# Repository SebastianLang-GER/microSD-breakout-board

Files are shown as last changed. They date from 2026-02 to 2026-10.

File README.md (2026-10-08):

# microSD breakout board
This is a compact microSD breakout board for both directions.  
It can also be used as a sniffer in between a host and a microSD card for analyzing signals or performing tests.  
The PCB is optimized for signal integrity with coplanar single ended impedance matching (50 Ω ±10 %).  

| Top | Bottom |
| :---: | :---: |
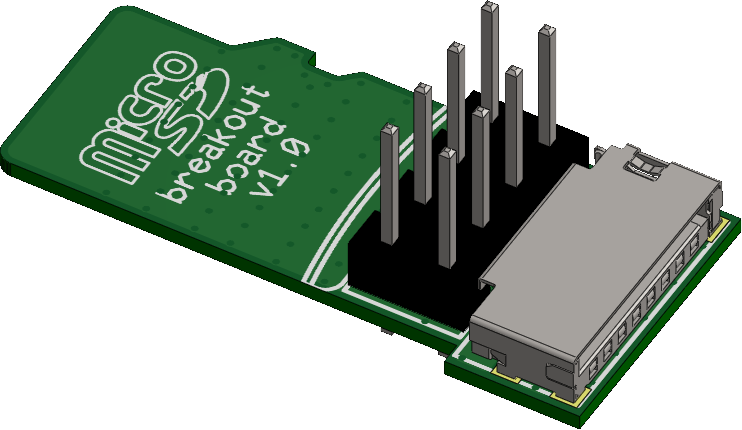
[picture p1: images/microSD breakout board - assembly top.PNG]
microSD breakout board
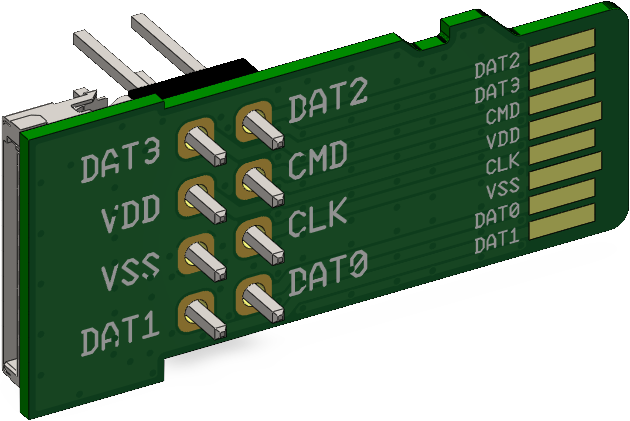
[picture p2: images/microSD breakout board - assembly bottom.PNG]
microSD breakout board
|  |  |

## Components  
Two optional components can be placed on the PCB:
- microSD card header `Molex 475710001`
- 2x4 2.54 mm pin header (e.g. `Molex 10897080`)

## Manufacturing
The PCB has the following properties:
- Size: 26.5 x 12.5 mm
- PCB thickness: 0.8 mm
- Layers: 2
- Copper weight: 1 oz
- Min. via hole size: ⌀ 0.3 mm
- Min. via diameter: ⌀ 0.4 mm
- Min. trace width: 0.4326 mm
- Min. distance between traces or pads: 0.127 mm
- Min. distance to board outline: 0.3 mm

Gerber files (RS-274X) are available [here](/electronics/production/).

The impedance was calculated for the standard 2 layer, 0.8 mm stack-up from JLCPCB: "JLC0208".

## Licence
This repository is in public domain.  
[Read more](/LICENSE)  
open source hardware logo

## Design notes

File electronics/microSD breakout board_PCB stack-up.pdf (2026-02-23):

PCB stack-up
Project: | microSD breakout board
Material: FR-4 | 0,716 mm
| mil | mm
Silkscreen | 0,1 0,003
Solder Mask | 0,4 0,010 | 3,8
1 | Copper | 0,6 0,015 | 1 oz
Core | 26 | 0,665 KB-6164 | 4,8 | 135 °C
2 | Copper | 0,6 0,015 | 1 oz
Solder Mask | 0,4 0,010 | 3,8
Silkscreen | 0,1 0,003

Solder Mask Bottom
Silkscreen Bottom

Thickness:
Name: | Layer: Type:
Silkscreen Top
Solder Mask Top
Copper Top

Dielectric

Copper Bottom

Material: | TG: Dk/εr: Weight:

Total Thickness:

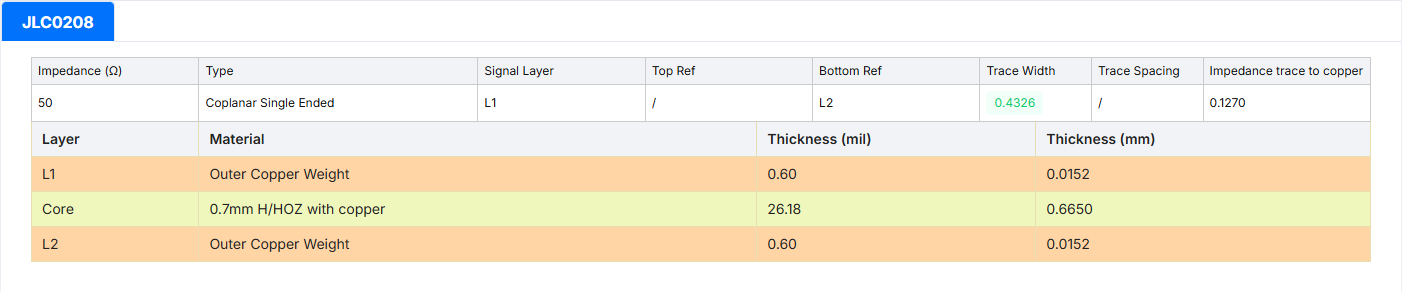
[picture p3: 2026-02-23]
electronics/microSD breakout board_impedance.png

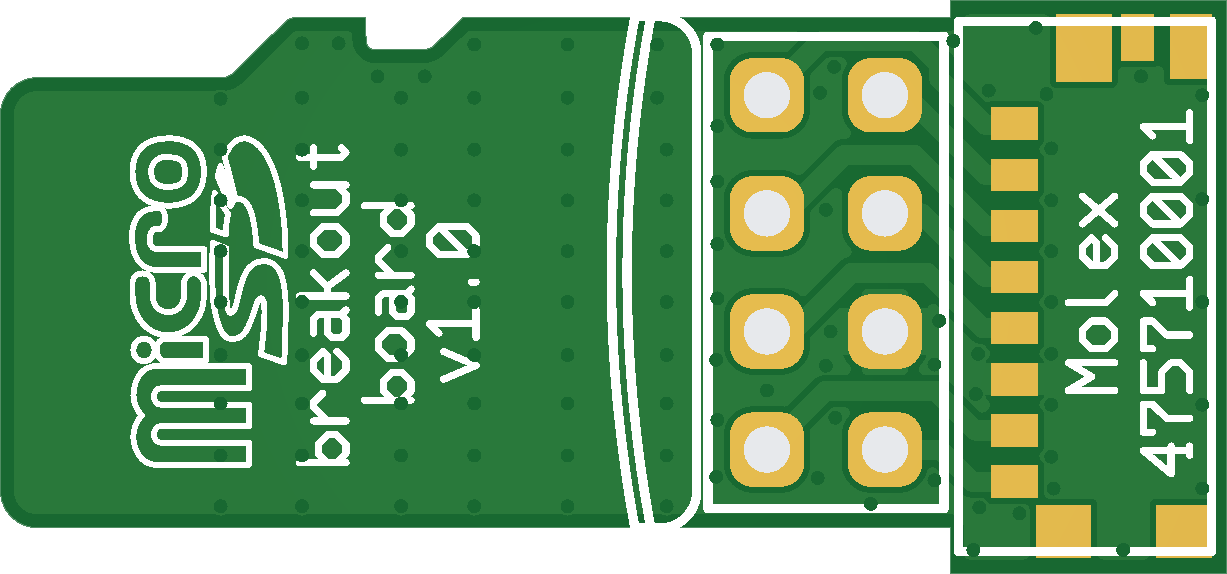
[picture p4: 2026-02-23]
images/microSD breakout board - PCB top.png

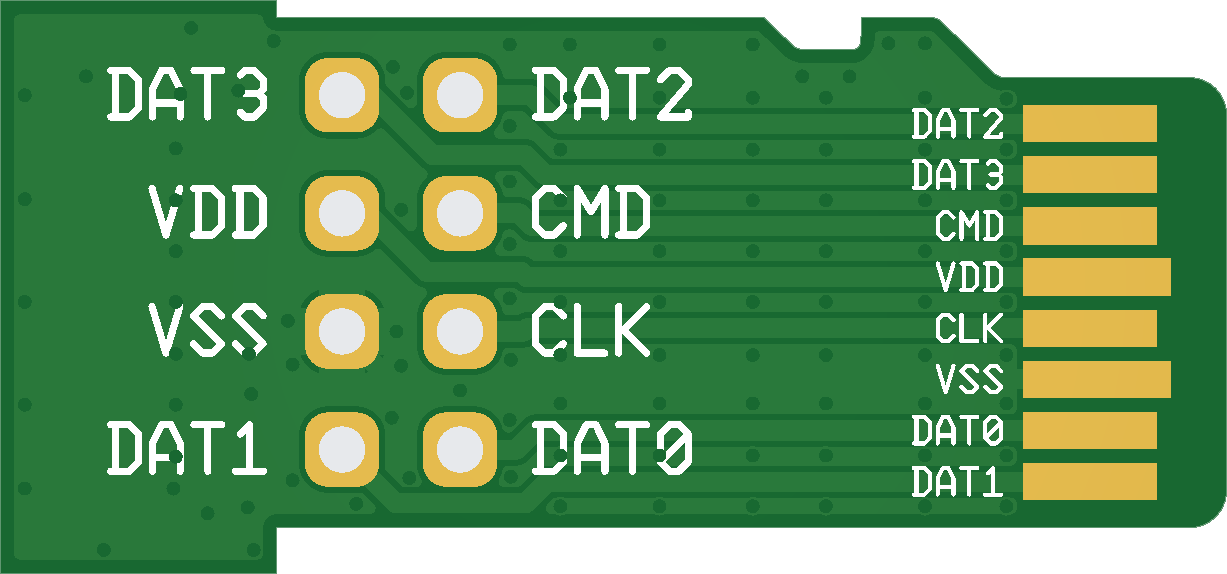
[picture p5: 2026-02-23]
images/microSD breakout board - PCB bottom.png

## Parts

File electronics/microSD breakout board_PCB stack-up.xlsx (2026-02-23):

PCB stack-up
Project: | microSD breakout board
Material: | FR-4 |  | Total Thickness: |  | 0.716 | mm
Name: |  | Layer: | Type: | Thickness: |  | Material: | Dk/εr: | Weight: | TG:
 |  |  |  | mil | mm
Silkscreen Top |  |  | Silkscreen | 0.1 | 0.003
Solder Mask Top |  |  | Solder Mask | 0.4 | 0.010 |  | 3.8
Copper Top |  | 1 | Copper | 0.6 | 0.015 |  |  | 1 oz
Dielectric |  |  | Core | 26.18 | 0.665 | KB-6164 | 4.8 |  | 135 °C
Copper Bottom |  | 2 | Copper | 0.6 | 0.015 |  |  | 1 oz
Solder Mask Bottom |  |  | Solder Mask | 0.4 | 0.010 |  | 3.8
Silkscreen Bottom |  |  | Silkscreen | 0.1 | 0.003

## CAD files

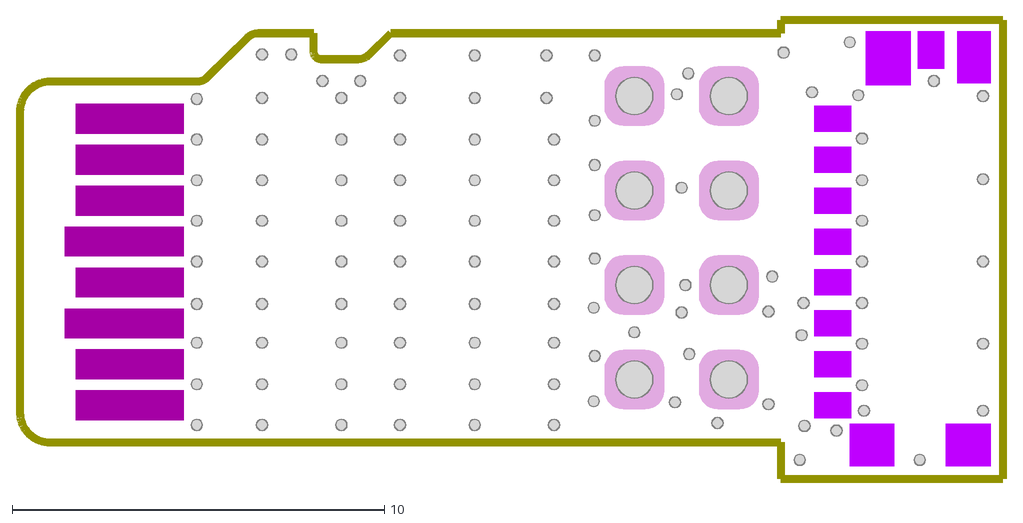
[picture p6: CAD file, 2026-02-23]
electronics/production/microSD breakout board.dxf
26.6 x 12.5

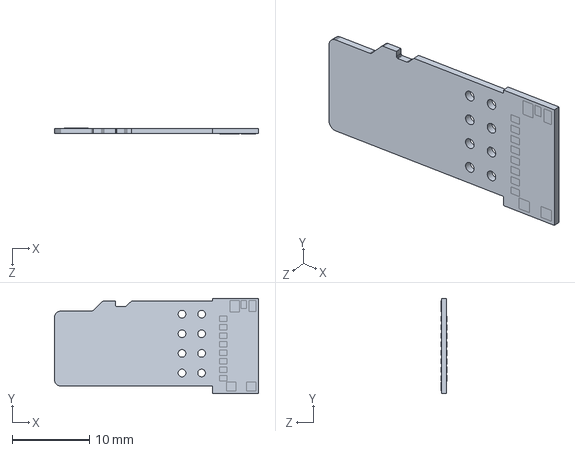
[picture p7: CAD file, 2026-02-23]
mechanics/PCB.SLDPRT
26.4 x 12.3 x 0.72 mm

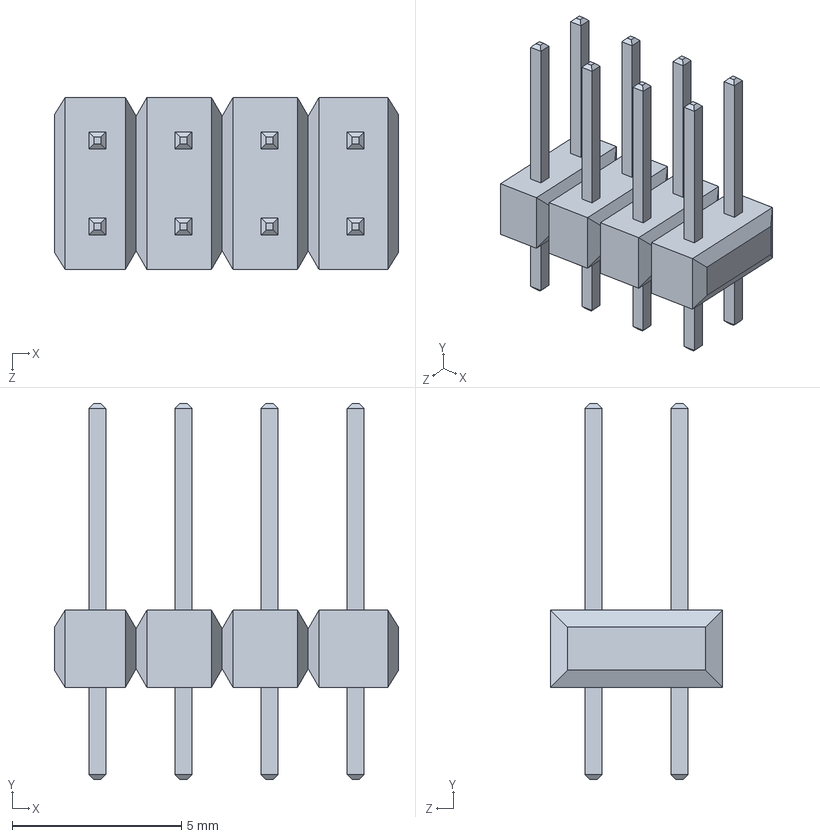
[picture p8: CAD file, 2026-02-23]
mechanics/Molex 10897080.SLDPRT
10.2 x 11.1 x 5.08 mm

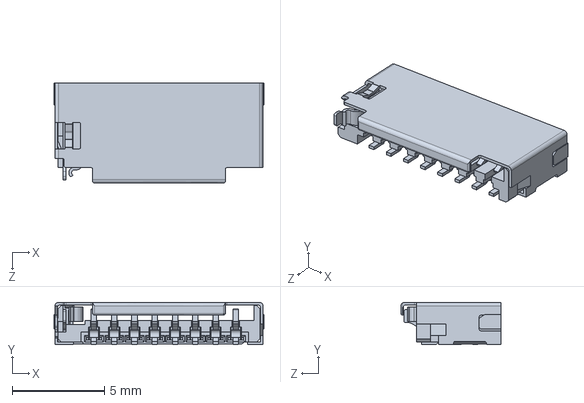
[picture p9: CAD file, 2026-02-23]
mechanics/Molex 475710001.SLDPRT
11.4 x 2.30 x 5.45 mm

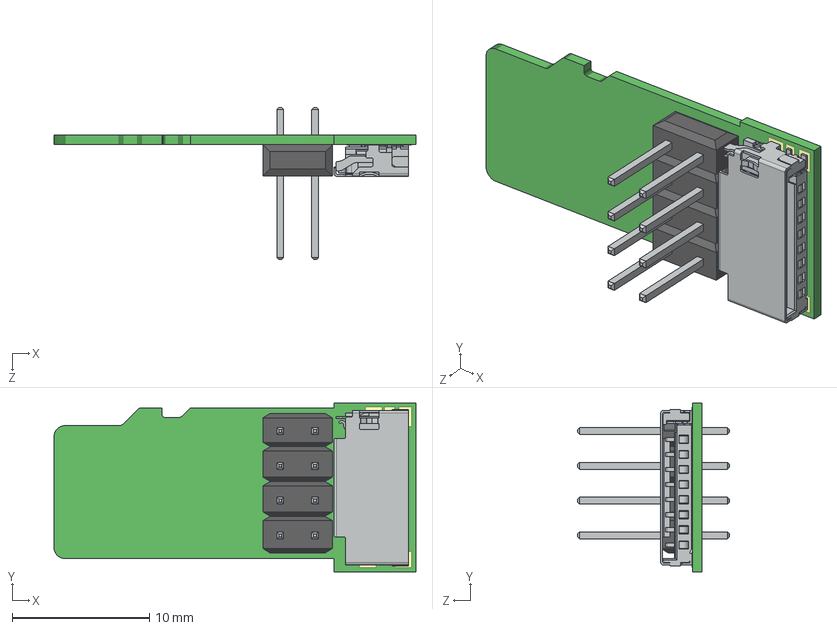
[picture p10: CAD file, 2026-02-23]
mechanics/microSD breakout board.STEP
26.4 x 12.3 x 11.1 mm
PCB
Molex 10897080
Molex 475710001

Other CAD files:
mechanics/microSD breakout board.SLDASM

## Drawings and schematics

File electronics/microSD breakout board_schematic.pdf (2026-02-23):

X2

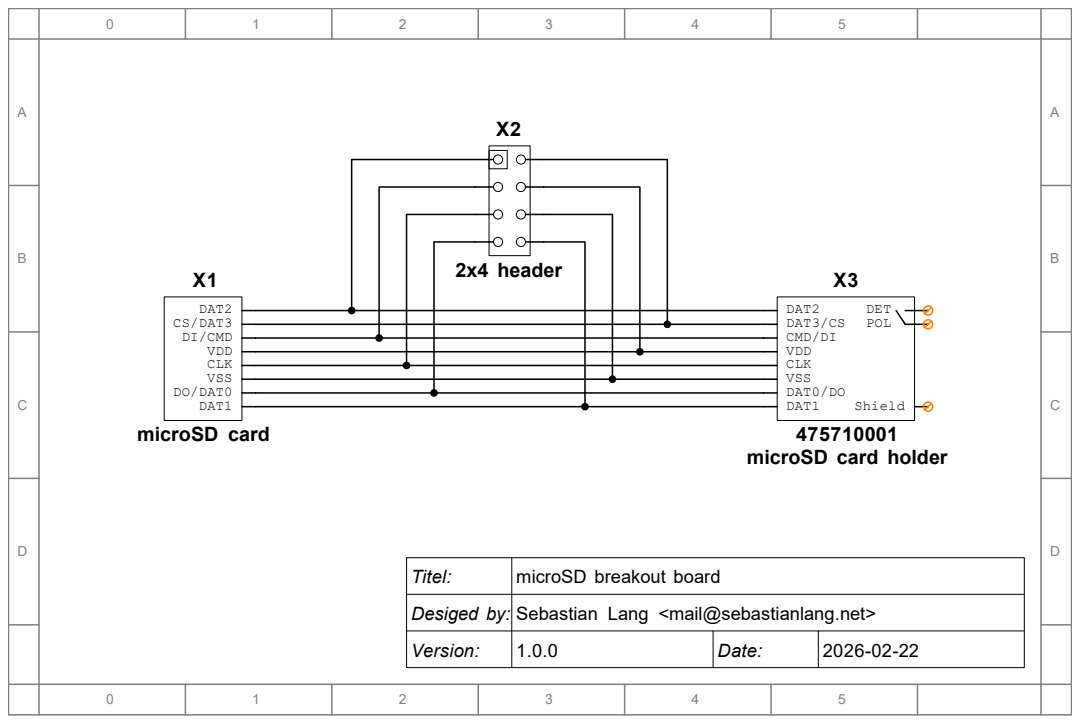
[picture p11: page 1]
D D Titel:; Desiged by:; Date:; Version:; microSD card; DAT2 CS/DAT3 DI/CMD VDD CLK VSS DO/DAT0 DAT1; 2x4 header; 475710001 microSD card holder; DAT2 DAT3/CS CMD/DI VDD CLK VSS DAT0/DO DAT1; POL; DET; Shield

microSD breakout board
Sebastian Lang <mail@sebastianlang.net>

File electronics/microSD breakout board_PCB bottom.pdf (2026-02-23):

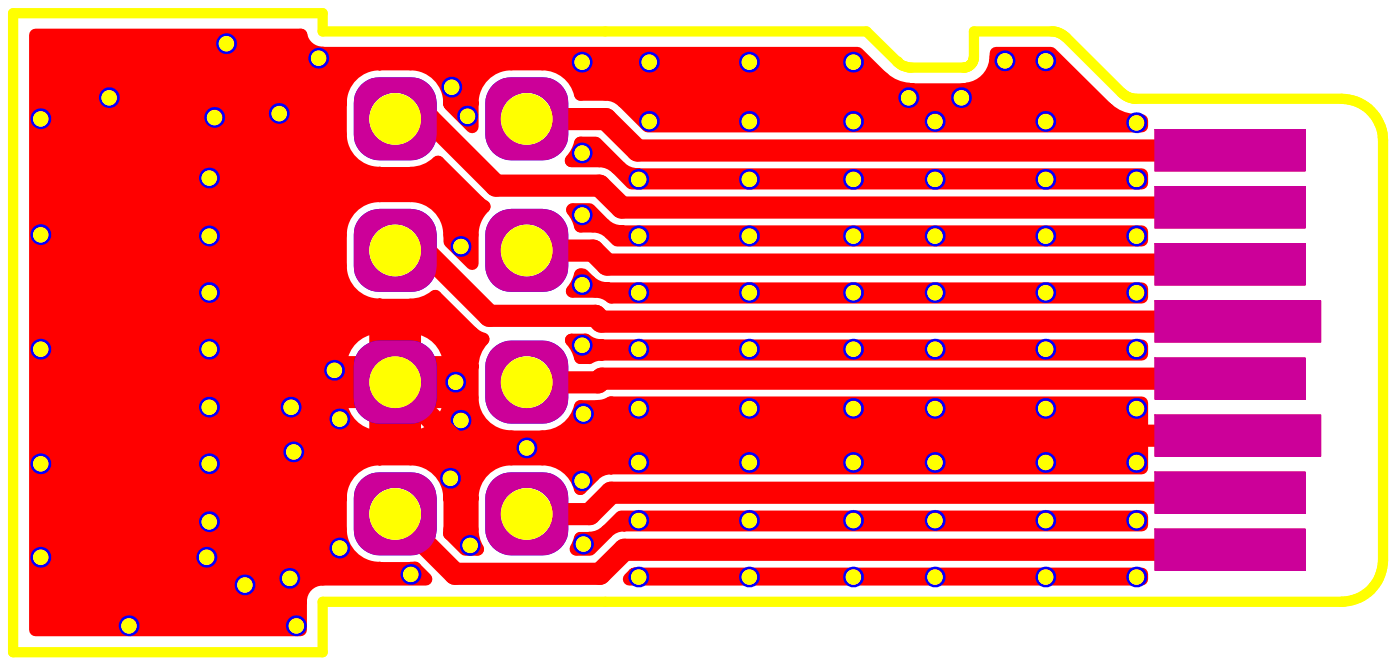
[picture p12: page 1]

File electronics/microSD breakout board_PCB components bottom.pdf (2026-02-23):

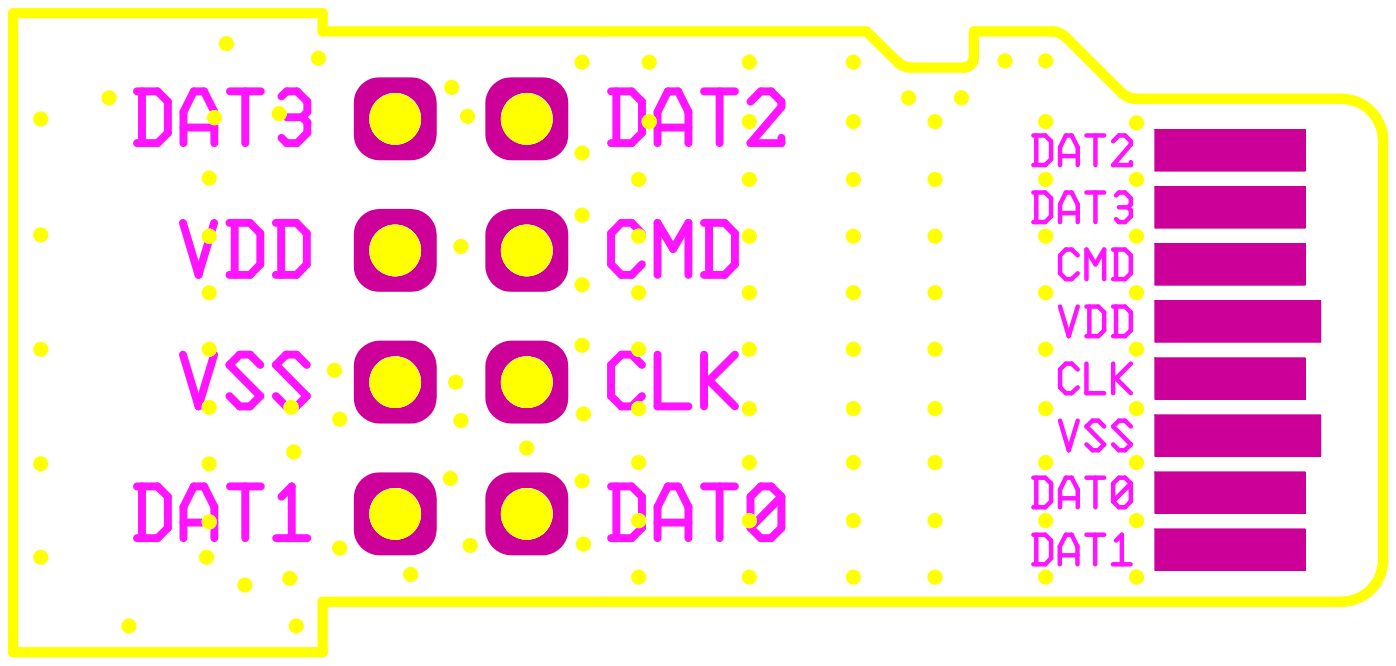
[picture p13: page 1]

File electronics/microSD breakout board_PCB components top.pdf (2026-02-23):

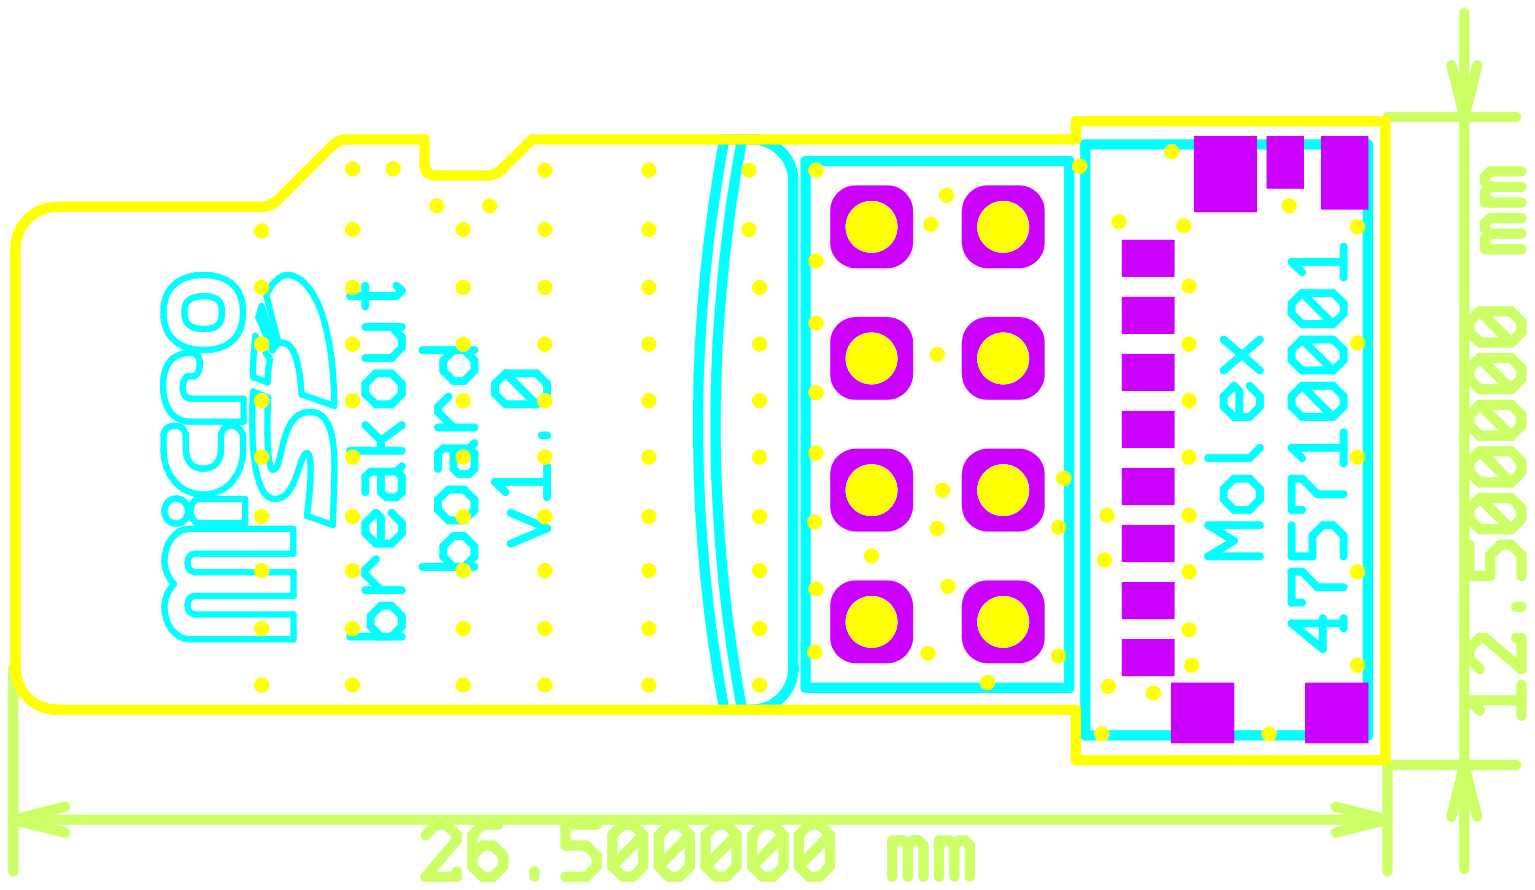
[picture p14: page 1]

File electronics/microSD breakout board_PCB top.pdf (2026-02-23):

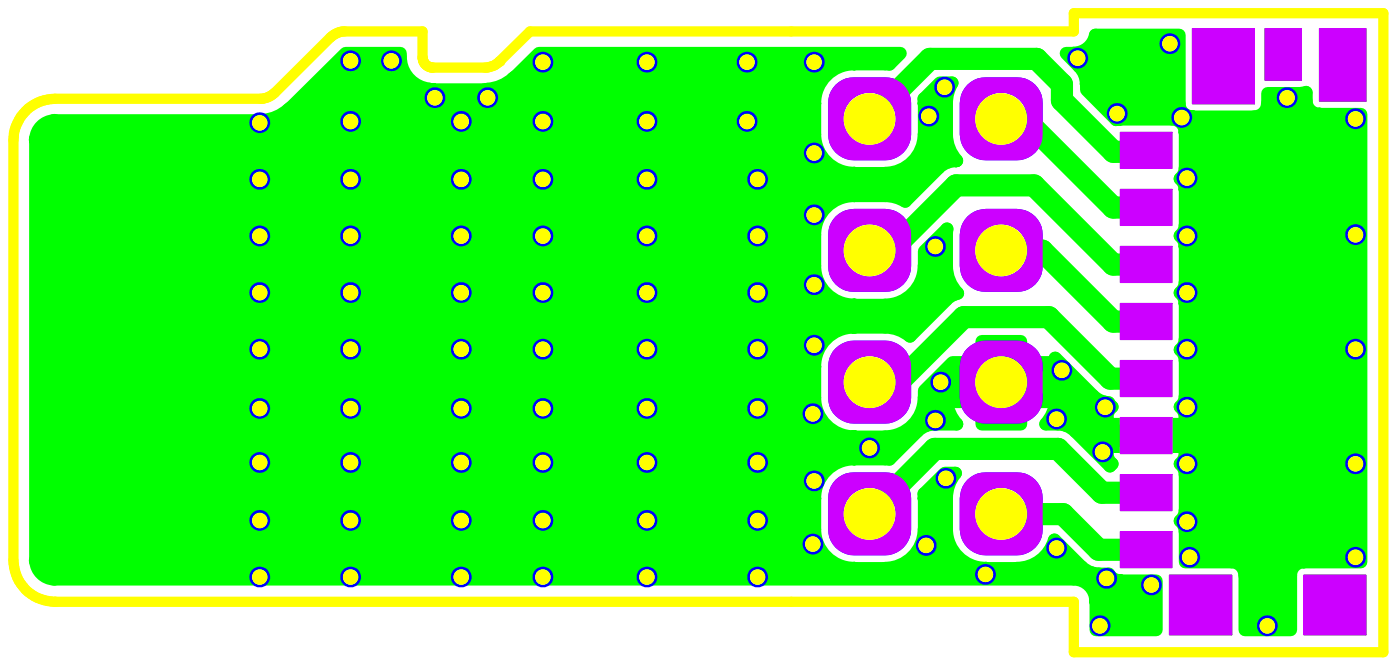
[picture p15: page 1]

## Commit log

2026-02-23 Files added
    Design files added (electronics, mechanics, datasheets, images)
    [Molex 10897080.SLDPRT, Molex 475710001.SLDPRT, PCB.SLDPRT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]
2026-02-23 Rename microSD breakout board_impeadance.png to microSD breakout board_impedance.png
    Correcting typo
2026-02-23 Update README.md
    Pin header type corrected to 2x4
